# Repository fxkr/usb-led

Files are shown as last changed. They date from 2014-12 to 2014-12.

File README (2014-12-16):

USB-RGB-LED
===========

A very simple + cheap + tiny USB-controllable RGB-LED.

Author: Felix Kaiser <felix.kaiser@fxkr.net>
License: GPLv2/GPLv3 (your choice)

Components:

- Board
- Firmware
- Linux tool

We use USB VID/PID f0ss:49d9 (screw you, USB-IF).

Thanks
------

This project is based on:

- Objective Developments V-USB (GPLv2/v3)
  http://www.obdev.at/products/vusb
- Micronucleus' RC Oscillator calibration routine (GPLv2/v3)
  https://github.com/micronucleus/micronucleus/blob/master/firmware/osccalASM.S
- libusb (LGPLv2.1 or later)
  http://libusb.info/
- SparkFuns Eagle Libraries (CC BY-SA 3.0)
  https://github.com/sparkfun/SparkFun-Eagle-Libraries

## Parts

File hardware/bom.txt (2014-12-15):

Part     Value    Package     Digikey      Qty  Price
IC1      Attiny8  8-SOIC      ATTINY85-20   1   1,36 €
C1       10uF     SMD 0805    1276-1119-1   1   0,17 €
C2       100nF    SMD 0603    399-1096-1-   1   0,09 €
D1, D2   ZD 3V6   SMD 0603    MM3Z3V6T1GO   2   0,13 €
R1, R2   68R      SMD 0603    P68GCT-ND     2   0,09 €
R3       1k5      SMD 0603    MCT0603-1.5   1   0,07 €
R4       470R     SMD 0603    MCT0603-470   1   0,07 €
R5       10K      SMD 0603    MCT0603-10.   1   0,07 €
USB               USB A Male  1175-1008-N   1   0,62 €
WS2812B  WS2812B  5050                      1   0,18 €

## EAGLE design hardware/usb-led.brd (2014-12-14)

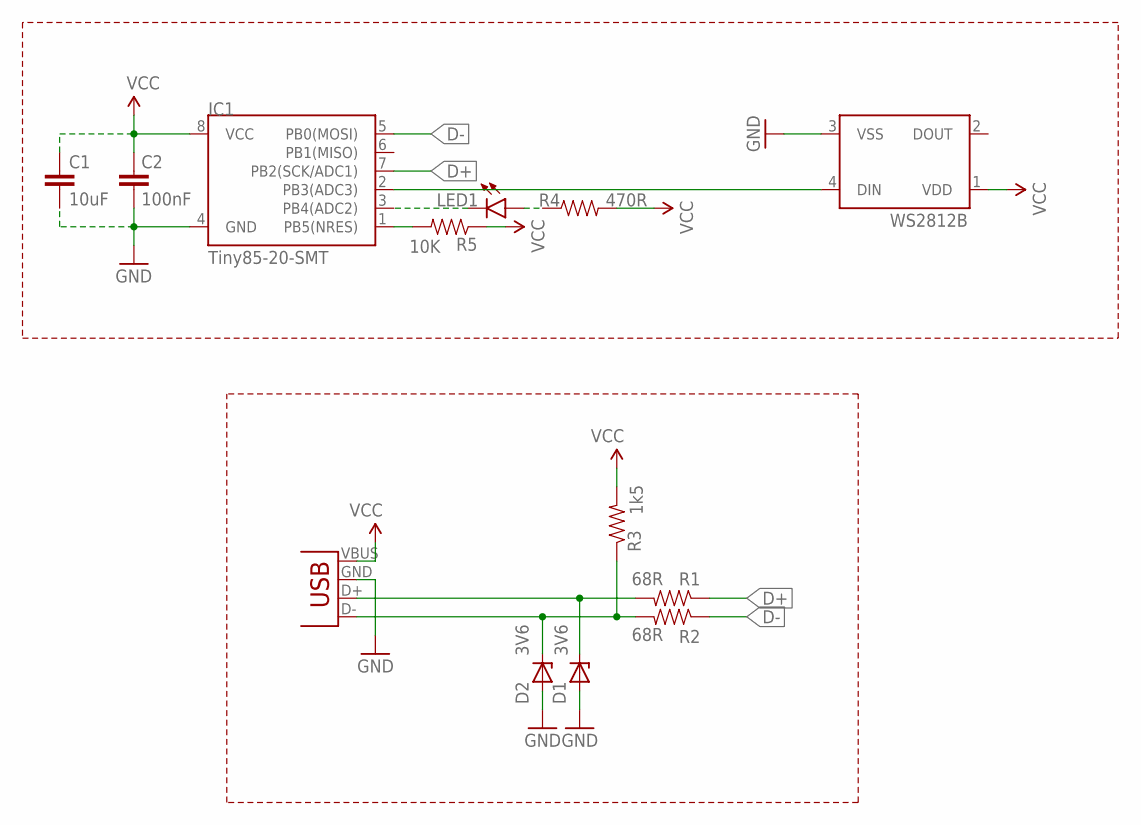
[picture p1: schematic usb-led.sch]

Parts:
C1: 10uF; C0805
C2: 100nF; 0805
D1, D2: 3V6; ZD0603
IC1: Tiny85-20-SMT; SO08-EIAJ
LED1: LED0603; LED-0603
R1, R2: 68R; 0603-RES
R3: 1k5; 0603-RES
R4: 470R; 0603-RES
R5: 10K; 0603-RES
USB: USB-A-H
WS2812B: WS2812B

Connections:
C10: IC1.1 (PB5(NRES)), R5.2
D+: IC1.7 (PB2(SCK/ADC1)), R1.1
D-: IC1.5 (PB0(MOSI)), R2.1
DIN: IC1.2 (PB3(ADC3)), WS2812B.4 (DIN)
EXT_D+: D1.K (C), R1.2, USB.D+ (D-)
EXT_D-: D2.K (C), R2.2, R3.1, USB.D- (D+)
GND: C1.2, C2.2, D1.A, D2.A, IC1.4 (GND), USB.GND (VBUS), WS2812B.3 (VSS)
unnamed: IC1.3 (PB4(ADC2)), LED1.C
unnamed: LED1.A, R4.1
VCC: C1.1, C2.1, IC1.8 (VCC), R3.2, R4.2, R5.1, USB.VBUS (GND), WS2812B.1 (VDD)

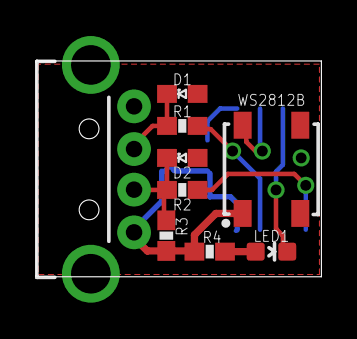
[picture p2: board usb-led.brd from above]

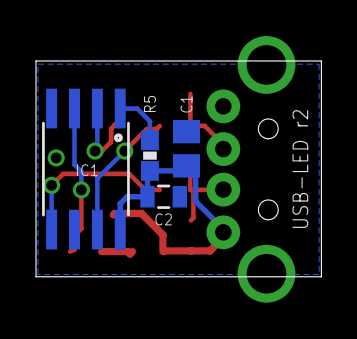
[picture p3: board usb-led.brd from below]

Board: 2 copper layers, 15.9 x 12.0 mm, 13 parts (4 on the bottom side), 10 nets.

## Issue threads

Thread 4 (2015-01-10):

LED doesn't stay off after power-on

fxkr, 2015-01-10:
Happens with the first r2 version I built; didn't happen with the r1.

fxkr, 2015-01-11:
Duplicate of #5

Closed 2015-01-11.

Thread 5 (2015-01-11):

rev2 doesn't work

fxkr, 2015-01-11:
Today I soldered two revision 2 pcbs.

For both, the firmware seemed to run fine (startup status led blinking was ok).
For the first one, USB worked but the green channel couldn't be enabled. Also, the LED would sometimes change color on its own. It had the new 3v6 ZD.
For the second one, USB didn't work either. It had the ZD from rev2 (3v3?).
For both, the LED would turn itself on after poweron.

Soldering in the 10uF cap didn't help.

Revision 1 worked so well...

:-(

fxkr, 2015-01-11:
- Are you sure you didn't put the ZDs in the wrong way?

fxkr, 2015-07-04:
* Did I get the fuses on the Attiny right?

fxkr, 2015-08-03:
* The fuses on my USB-LED are right.
* But the LED looks slightly different than the one I have on the working rev1.

fxkr, 2015-08-28:
Something must be wrong with these LEDs.

First of all, it doesn't even look like a WS2812B or anything similiar. In fact I couldn't find any LED on the internet that looks exactly like my LED.

I measured the output with the logic analyzer, and the timing matches the code, so there's nothing wrong with the uC.

I then brute-forced all possible combinations of delays (for a²+b²+c<107 where a/b/c = number of nops before early falling edge and before and after the late falling edge) and I couldn't get the LEDs to light up.

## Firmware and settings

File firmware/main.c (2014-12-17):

#include <avr/interrupt.h>
#include <stdbool.h>
#include <stdint.h>
#include <util/delay.h>

#include "usbconfig.h"
#include "usbdrv/usbdrv.h"

#include "osccal.h"
#include "ws2812b.h"
#include "timer.h"


#define STATUS_LED_PIN      PB4
#define STATUS_LED_PORT     PORTB
#define STATUS_LED_DDR      DDRB
#define STATUS_LED_DDR_MASK (1 << STATUS_LED_PIN)


typedef struct {
  // Buffered red/green/blue channel and status led values
  uint16_t red, green, blue;
  uint8_t status;  // 0 = off, 1 = on, 2 = blink

  // Fading parameters
  uint16_t red_target, green_target, blue_target, fade_rate;

  // Blinking parameters
  uint16_t blink_duty, blink_period;
} state_t;


state_t global_state = {
  .fade_rate = 256,
};


/* Turn the green status LED on/off. */
void set_status_led(bool on_off)
{
  if (on_off) {
    STATUS_LED_PORT &= ~(1 << STATUS_LED_PIN);
  } else {
    STATUS_LED_PORT |= (1 << STATUS_LED_PIN);
  }
}

// usbFunctionSetup handles USB Control Transfers.
extern usbMsgLen_t usbFunctionSetup(uchar setupData[8])
{
  // Verify checksum. V-USB doesn't do it.
  // (Yes, this out-of-bounds access is ok.)
  if (usbCrc16(setupData, 8 + 2) != 0x4FFE) {
    return 0;  // CRC error; ignore packet
  }

  usbRequest_t *rq = (void *)setupData;

  switch(rq->bRequest){

    // Turn everything off
    case 0:
      global_state.red = 0;
      global_state.green = 0;
      global_state.blue = 0;
      global_state.red_target = 0;
      global_state.green_target = 0;
      global_state.blue_target = 0;
      global_state.status = 0;
      // fall-through

    // Make updates take effect (and stops all fading)
    case 1:
      set_status_led(global_state.status == 1);
      ws2812b_set_rgb(global_state.red, global_state.green, global_state.blue);
      global_state.red_target = global_state.red;
      global_state.green_target = global_state.green;
      global_state.blue_target = global_state.blue;
      return 0;

    // Status LED
    case 2:
      global_state.status = rq->wValue.word & 0xff;
      return 0;

    // Set channel values immediately (and stops all fading)
    case 3:
      global_state.red = rq->wValue.word;
      global_state.red_target = global_state.red;
      global_state.green_target = global_state.green;
      global_state.blue_target = global_state.blue;
      return 0;
    case 4:
      global_state.green = rq->wValue.word;
      global_state.red_target = global_state.red;
      global_state.green_target = global_state.green;
      global_state.blue_target = global_state.blue;
      return 0;
    case 5:
      global_state.blue = rq->wValue.word;
      global_state.red_target = global_state.red;
      global_state.green_target = global_state.green;
      global_state.blue_target = global_state.blue;
      return 0;

    // Fade channel values
    case 6:
      global_state.red_target = rq->wValue.word;
      return 0;
    case 7:
      global_state.green_target = rq->wValue.word;
      return 0;
    case 8:
      global_state.blue_target = rq->wValue.word;
      return 0;

    // Fade speed (16-bit-value per millisec)
    case 9:
      if (rq->wValue.word > 0) {
        global_state.fade_rate = rq->wValue.word;
      } else {
        global_state.red_target = global_state.red;
        global_state.green_target = global_state.green;
        global_state.blue_target = global_state.blue;
      }
      return 0;

    // Blink rate speed (16-bit-value per millisec)
    case 10:
      global_state.blink_duty = rq->wValue.word;
      global_state.blink_period = rq->wIndex.word;
      if (global_state.blink_period == 0) {
        ws2812b_set_rgb(global_state.red, global_state.green, global_state.blue);
      }
      return 0;

    // Ignore unknown requests
    default:
      return 0;
  }
}

// hadUsbReset calibrates the internal 16 MHz RC oscillator to run at the
// 16.5 MHz needed by V-USB after reset.
extern void hadUsbReset() {
  calibrateOscillatorASM();
}

// fade_to makes channels value closer to target.
// Returns true if *channel was changed, false otherwise.
bool fade_to(uint16_t *channel, uint16_t target) {

  // No fading necessary?
  if (*channel == target) {
    return false;

  // Fade up or down?
  } else if (*channel < target) {
    uint16_t delta = target - *channel;
    if (delta > global_state.fade_rate) delta = global_state.fade_rate;
    *channel += delta;
  } else {
    uint16_t delta = *channel - target;
    if (delta > global_state.fade_rate) delta = global_state.fade_rate;
    *channel -= delta;
  }

  return true;
}

int main(void) {

  // Set clock prescaler to 1 (so we'll run at 16 MHz; we'll switch to 16.5 MHz later).
  // Not actually necessary if the CKDIV8 fuse is programmed.
  CLKPR = 1<<CLKPCE;  // enable change
  CLKPR = 0;  // set factor to 1

  // Configure indicator LED pin
  STATUS_LED_DDR |= STATUS_LED_DDR_MASK;

  // Make sure the big LED is off
  ws2812b_set_rgb(0,0,0);

  // Blink small led as boot indication
  set_status_led(true);
  _delay_ms(33);
  set_status_led(false);
  _delay_ms(33);
  set_status_led(true);
  _delay_ms(33);
  set_status_led(false);

  timer_init();

  // Initialize USB and reenumerate
  usbInit();
  usbDeviceDisconnect();
  _delay_ms(250);
  usbDeviceConnect();
  sei(); // Enable interrupts. By now, all other initialization should be done.
  usbPoll();

  while (1) {
    usbPoll();

    // New millisecond?
    time_val_t now = timer_get();
    if (now.updated) {
      bool update = false;

      // Fading
      update |= fade_to(&global_state.red, global_state.red_target);
      update |= fade_to(&global_state.green, global_state.green_target);
      update |= fade_to(&global_state.blue, global_state.blue_target);

      // Blinking
      uint16_t r = global_state.red, g = global_state.green, b = global_state.blue;
      if (global_state.blink_period != 0) {
        if (now.time % global_state.blink_period == 0) {
          update = true;
        } else if (now.time % global_state.blink_period == global_state.blink_duty) {
          r = 0;
          g = 0;
          b = 0;
          update = true;
        }
      }

      if (update) {
        ws2812b_set_rgb(r, g, b);
      }

      // Status LED
      if (global_state.status == 2) {
        if (now.time % 1000 == 0) {
          set_status_led(true);
        } else if (now.time % 1000== 10) {
          set_status_led(false);
        }
      }
    }
  }

  return 0;
}

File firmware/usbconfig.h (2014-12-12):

#ifndef __usbconfig_h_included__
#define __usbconfig_h_included__

/*
General Description:
This file is an example configuration (with inline documentation) for the USB
driver. It configures V-USB for USB D+ connected to Port D bit 2 (which is
also hardware interrupt 0 on many devices) and USB D- to Port D bit 4. You may
wire the lines to any other port, as long as D+ is also wired to INT0 (or any
other hardware interrupt, as long as it is the highest level interrupt, see
section at the end of this file).
+ To create your own usbconfig.h file, copy this file to your project's
+ firmware source directory) and rename it to "usbconfig.h".
+ Then edit it accordingly.
*/

/* ---------------------------- Hardware Config ---------------------------- */

#define USB_CFG_IOPORTNAME      B
/* This is the port where the USB bus is connected. When you configure it to
 * "B", the registers PORTB, PINB and DDRB will be used.
 */
#define USB_CFG_DMINUS_BIT      0
/* This is the bit number in USB_CFG_IOPORT where the USB D- line is connected.
 * This may be any bit in the port.
 */
#define USB_CFG_DPLUS_BIT       2
/* This is the bit number in USB_CFG_IOPORT where the USB D+ line is connected.
 * This may be any bit in the port. Please note that D+ must also be connected
 * to interrupt pin INT0! [You can also use other interrupts, see section
 * "Optional MCU Description" below, or you can connect D- to the interrupt, as
 * it is required if you use the USB_COUNT_SOF feature. If you use D- for the
 * interrupt, the USB interrupt will also be triggered at Start-Of-Frame
 * markers every millisecond.]
 */
#define USB_CFG_CLOCK_KHZ       (F_CPU/1000)
/* Clock rate of the AVR in kHz. Legal values are 12000, 12800, 15000, 16000,
 * 16500, 18000 and 20000. The 12.8 MHz and 16.5 MHz versions of the code
 * require no crystal, they tolerate +/- 1% deviation from the nominal
 * frequency. All other rates require a precision of 2000 ppm and thus a
 * crystal!
 * Since F_CPU should be defined to your actual clock rate anyway, you should
 * not need to modify this setting.
 */
#define USB_CFG_CHECK_CRC       0
/* Define this to 1 if you want that the driver checks integrity of incoming
 * data packets (CRC checks). CRC checks cost quite a bit of code size and are
 * currently only available for 18 MHz crystal clock. You must choose
 * USB_CFG_CLOCK_KHZ = 18000 if you enable this option.
 */

/* ----------------------- Optional Hardware Config ------------------------ */

/* #define USB_CFG_PULLUP_IOPORTNAME   D */
/* If you connect the 1.5k pullup resistor from D- to a port pin instead of
 * V+, you can connect and disconnect the device from firmware by calling
 * the macros usbDeviceConnect() and usbDeviceDisconnect() (see usbdrv.h).
 * This constant defines the port on which the pullup resistor is connected.
 */
/* #define USB_CFG_PULLUP_BIT          4 */
/* This constant defines the bit number in USB_CFG_PULLUP_IOPORT (defined
 * above) where the 1.5k pullup resistor is connected. See description
 * above for details.
 */

/* --------------------------- Functional Range ---------------------------- */
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

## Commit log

2014-07-19 Import schematic + board
    [usb-led.brd, usb-led.sch]
2014-07-19 Forgot two 3.6V Z-Diodes
    [usb-led.brd, usb-led.sch]
2014-10-03 Use real USB connector, not PCB-trace-based one
    OSHPark PCBs are not thick enoguh (1.5mm, not 2.4mm)
    [usb-led.brd, usb-led.sch]
2014-10-03 Add r1 label
    [usb-led.brd]
2014-10-04 Fix silkscreen
    [usb-led.brd]
2014-12-12 Move brd/sch to hardware/
    [usb-led.brd, usb-led.sch]
2014-12-13 Hardware: revision 2
    - Fix: WS2812Bs DIN/DOUT pins were swapped. This was a bug in
    SparkFuns eagle library (fixed in latest version).
    - Smaller board: border now cuts through USB plug mounting via.
    OSHPark support said it's fine. We'll see.
    If it doesn't work, I'll have to either use the larger board size,
    find an (expensive) SMD male USB A connector or use a PCB connector
    (and switch to a fab that supports 2.4mm thick boards).
    - No 0402 components (R, ZD) anymore. The smallest are 0603 now.
    I can solder 0402, but it's not very beginner-friendly.
    - Add 0805 10uF bulk capacitance, just in case. It seems to work fine
    without, so it doesn't need to be populated. (Cost: 18ct at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
    [usb-led.brd, usb-led.sch]
2014-12-13 Firmware: check checksum of USB packets
    This only checks USB Control Transfer packets.
    In particular, it doesn't check packets v-usb handles internally.
    But it's better than nothing.
    [main.c]
2014-12-14 Firmware: add time measurement
    We now count the number of milliseconds since boot.
    As a test, we blink the status LED every second.
2014-12-14 Hardware: rename parts
    [usb-led.brd, usb-led.sch]
2014-12-14 Hardware: more space for the Zener diodes
    Their case is a a little bit larger than the normal 0603 footprint.
    [usb-led.brd, usb-led.sch]
2014-12-15 Hardware: add BOM
    Please don't actually buy single 0603 100nF capacitors.
2014-12-16 Firmware/Tool: Status led: Add off/on/blink choice
2014-12-17 Firmware: Fix: add missing return in a case branch
    [main.c]

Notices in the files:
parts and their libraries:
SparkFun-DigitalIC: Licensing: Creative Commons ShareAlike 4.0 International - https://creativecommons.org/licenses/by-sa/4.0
